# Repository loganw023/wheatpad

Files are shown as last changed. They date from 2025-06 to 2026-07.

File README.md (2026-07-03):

# wheatpad
This is a macropad for personal use. It has six keys, a rotary encoder with a switch, and an OLED screen. I used KMK firmware to code the macropad. I used the macropad as an introduction to PCB design and to increase my CAD experience. 

## Build Photo


## CAD
I used Fusion360 to create my macropad case. There are two parts: a bottom and a top. In the physical model, the PCB will be moved up to allow enough space for keycaps to be pressed. 
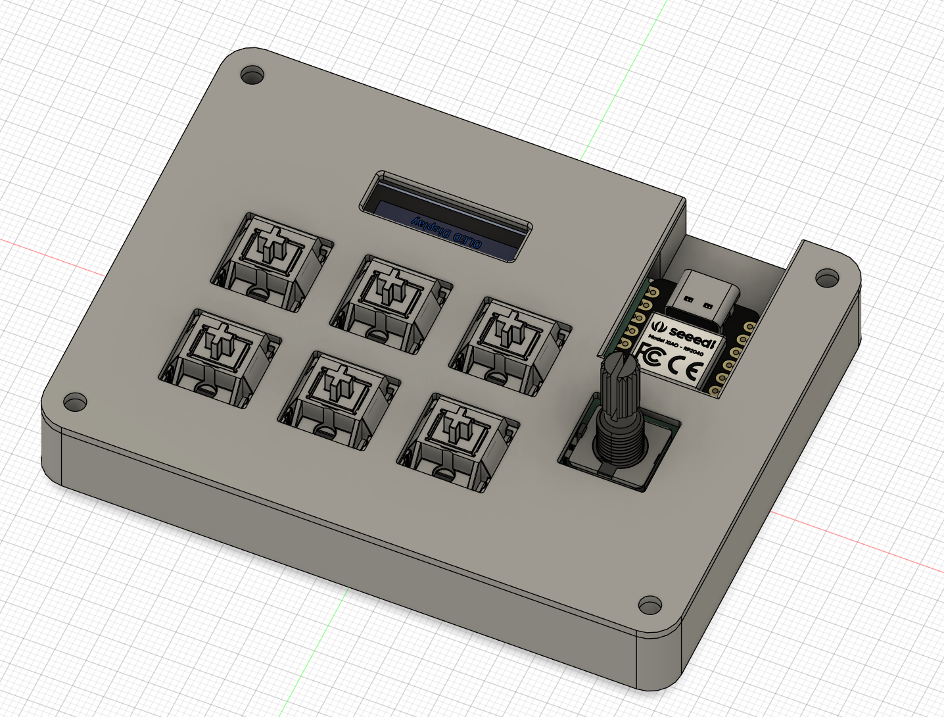
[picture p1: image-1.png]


## PCB
Schematic: 
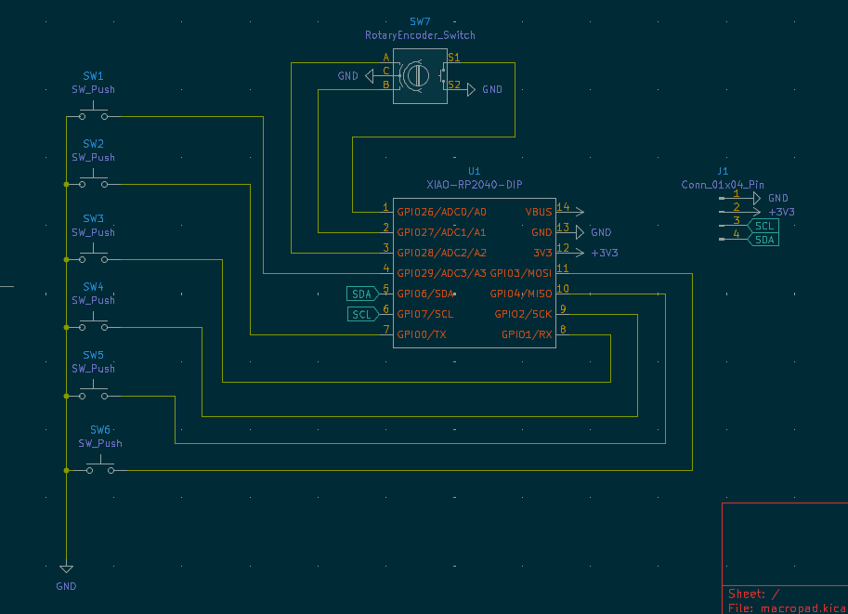
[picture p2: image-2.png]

PCB:
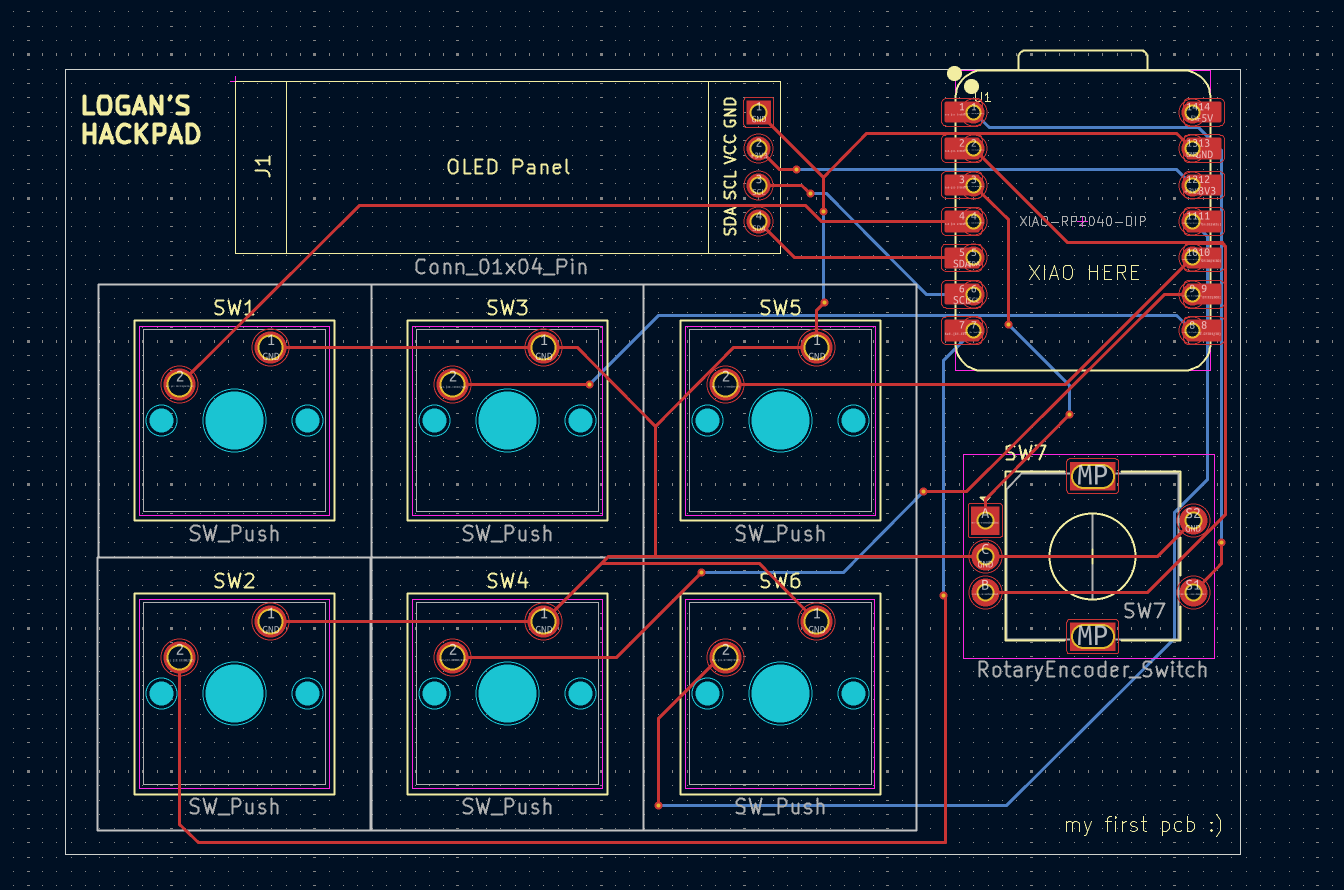
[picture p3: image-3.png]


## Firmware
I updated the firmware for the finished product! 

## BOM
* 6x Cherry MX Switches
* 6x DSA Keycaps
* 4x M3x5x4 Heatset inserts
* 4x M3x16mm SHCS Bolts
* 1x 0.91" 128x32 OLED Display
* 1x EC11 Rotary Encoder
* 1x XIAO RP2040
* 1x Case (2 printed parts)
* 1x Custom PCB

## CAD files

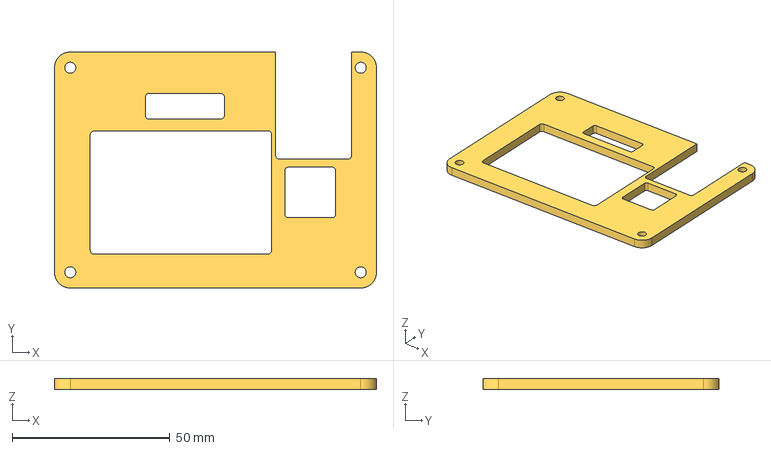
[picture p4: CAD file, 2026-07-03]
CAD/newLid.step
102.0 x 74.8 x 3.50 mm

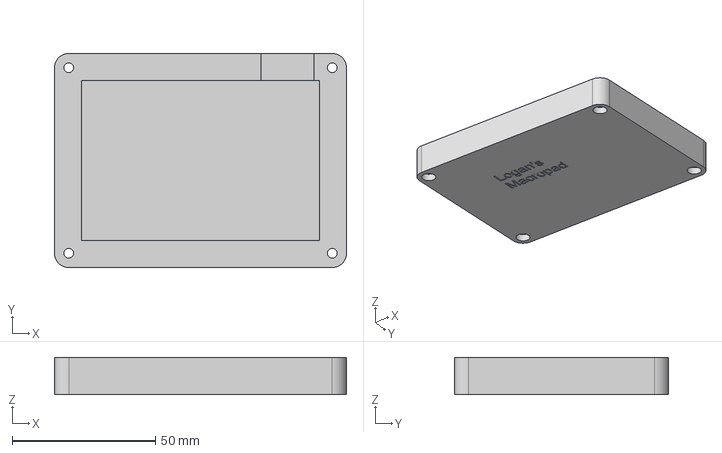
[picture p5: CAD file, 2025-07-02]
Production/Bottom.step
102.0 x 74.8 x 13.0 mm

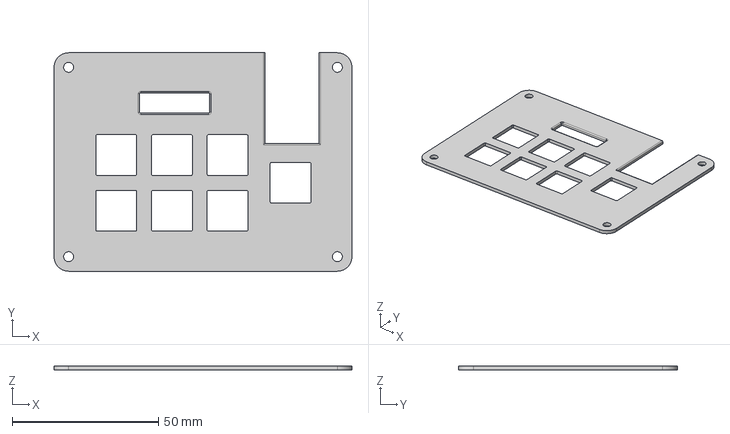
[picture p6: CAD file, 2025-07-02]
Production/Top.step
102.0 x 74.8 x 1.50 mm

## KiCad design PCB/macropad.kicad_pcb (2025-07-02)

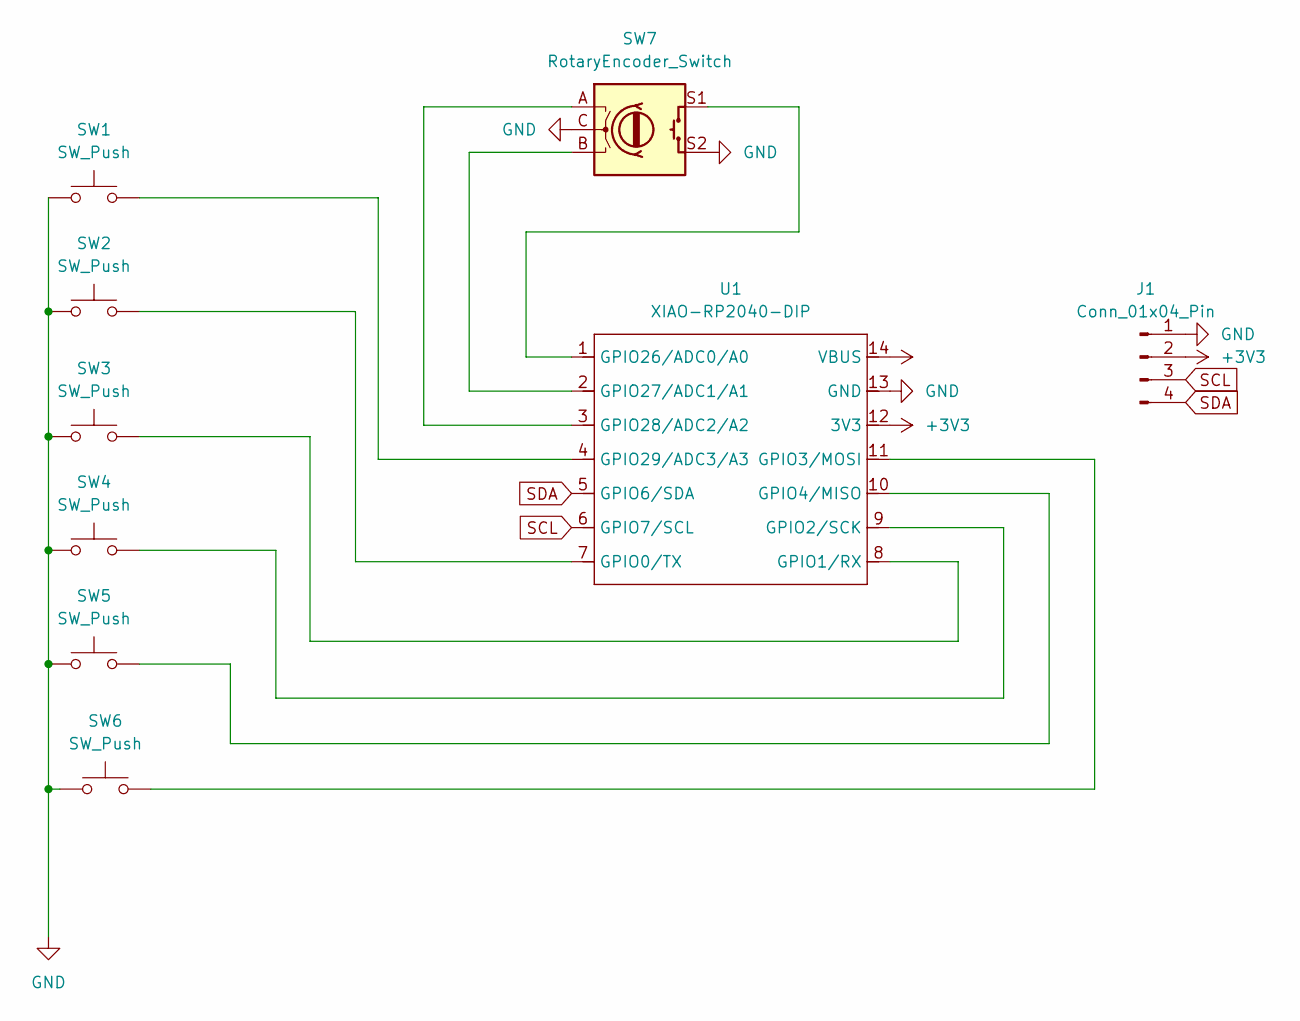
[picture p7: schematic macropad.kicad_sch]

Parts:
J1: Conn_01x04_Pin; SSD1306-0.91-OLED-4pin-128x32
SW1, SW2, SW3, SW4, SW5, SW6: SW_Push; SW_Cherry_MX_1.00u_PCB
SW7: RotaryEncoder_Switch; RotaryEncoder_Alps_EC11E-Switch_Vertical_H20mm
U1: XIAO-RP2040-DIP

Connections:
+3V3: J1.2, U1.12 (3V3)
+5V: U1.14 (VBUS)
GND: J1.1, SW1.1, SW2.1, SW3.1, SW4.1, SW5.1, SW6.1, SW7.C, SW7.S2, U1.13 (GND)
unnamed: SW2.2, U1.7 (GPIO0/TX)
unnamed: SW3.2, U1.8 (GPIO1/RX)
unnamed: SW4.2, U1.9 (GPIO2/SCK)
unnamed: SW6.2, U1.11 (GPIO3/MOSI)
unnamed: SW5.2, U1.10 (GPIO4/MISO)
unnamed: SW7.S1, U1.1 (GPIO26/ADC0/A0)
unnamed: SW7.B, U1.2 (GPIO27/ADC1/A1)
unnamed: SW7.A, U1.3 (GPIO28/ADC2/A2)
unnamed: SW1.2, U1.4 (GPIO29/ADC3/A3)
SCL: J1.3, U1.6 (GPIO7/SCL)
SDA: J1.4, U1.5 (GPIO6/SDA)

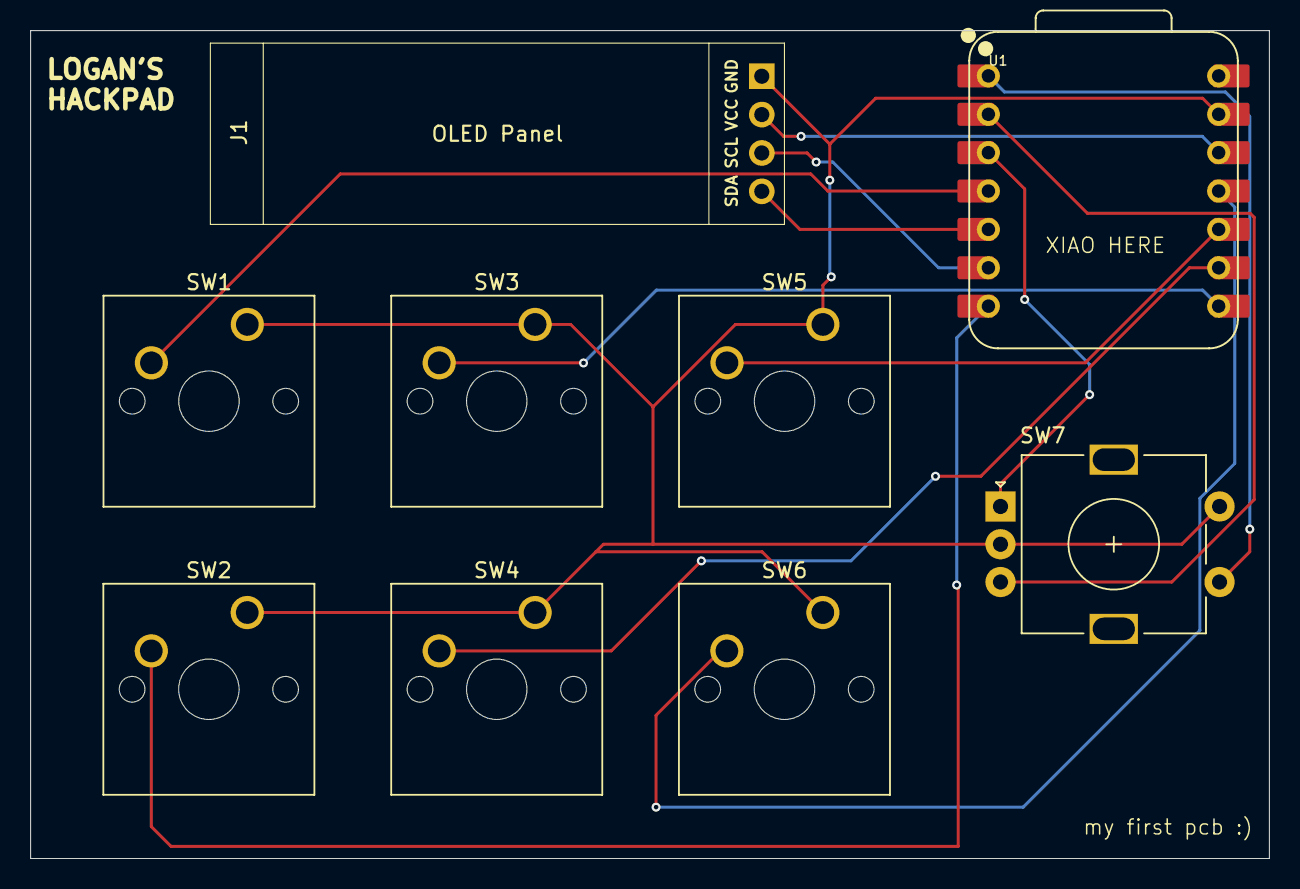
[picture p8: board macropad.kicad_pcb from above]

Board: 2 copper layers, 82.0 x 54.8 mm, 9 parts (0 on the bottom side), 13 nets.

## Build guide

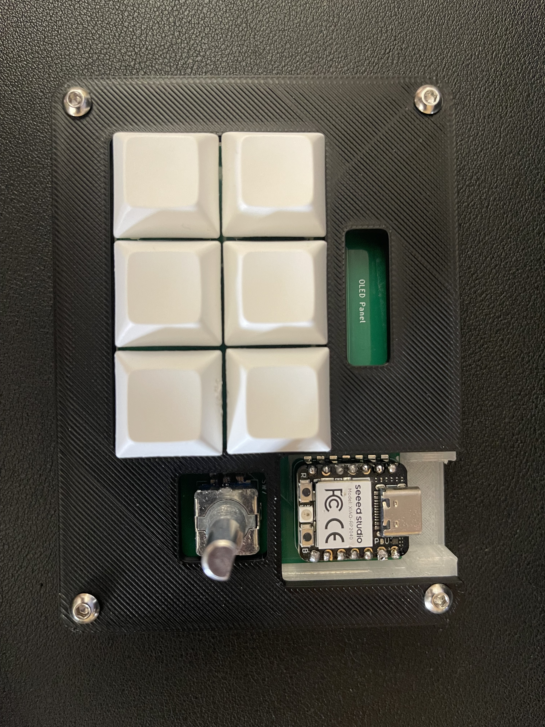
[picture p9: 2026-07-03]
Build Photos/IMG_4601.jpeg

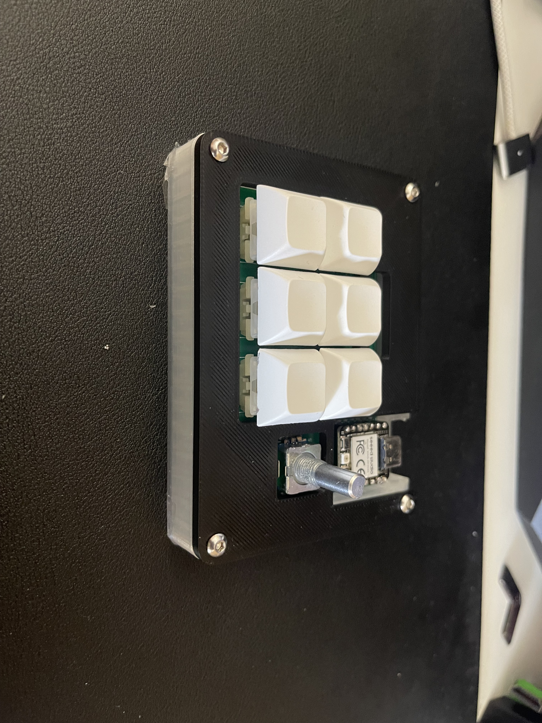
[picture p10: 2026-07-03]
Build Photos/IMG_4600.jpeg

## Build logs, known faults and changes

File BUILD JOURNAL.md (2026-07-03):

# Build Journal

This project is from highway. Last summer, I soldered all the components down onto the PCB, installed circuitpython and copied the firmware, but the macropad did not work, so I put the project on hold for a while. I only picked up the project and finished it during outpost, in which I started building 07/02/2026, and finished 07/03/2026. 

## 07/02/2026

The work outlined was not thoroughly documented, and I only took a few pictures of the end product. The work outlined took place from around 4 pm to 10 pm which entails the troubleshooting effort leading towards a working end item. 

Today, I started by plugging in the macropad, but noticed that the macropad did not work. I ended up fixing a bunch of soldering joints that were poorly done last summer, which I think are a lot cleaner now. When plugging in the macropad again, I noticed that nothing worked. I first thought that this was a firmware issue, so I went through many iterations of the code to attempt to fix the issue, but none of these coding changes caused the macropad to work. When soldering, I realized that I accidently connected two soldering joints on the rotary encoder, being GND and Pin A, which I thought was the issue. I then spent an hour attempting to separate the two joints from each other, which I managed to do, but I destroyed the rotary encoder pins. When going back, I again realized that NOTHING worked once again. From here, I decided to use a multimeter to check if electricity could flow throughout the PCB. I proceeded to perform continuity mode tests as well as accidental ground short tests. The PCB passed all these tests, which made me more confused. I then thought that the issue was the pin assignments, but that also wasn't the issue. I ended up using a paper clip to act as a bridge between the XIAO GND pin and certain GPIO pins mapped to the switches on the XIAO, which caused the letters to be printed, which helped me determine that the issue was most likely broken traces on the PCB, specifically the common GND trace that all my switches were connected to. From here, I used a wire I had from an introductory arduino kit and soldered it between one of the switch's GND pin and the XIAO GND pin. This caused the switches to work. 

## 07/03/2026

Today, I cleaned up the GND wire I added to be more discrete to allow the PCB to fit in the case, and put the PCB in the case and screwed the lid onto the bottom. I realized that I lost the OLED screen the kit came with, but ultimately the screen was not essential to the functionality of the product, so I think it's fine without the OLED. Additionally, the rotary encoder does not work still, which I think is not only because of the mishap with the soldering job, but also because of issues with the traces on the PCB. In the end, the switches still work, which is the main purpose of the macropad for me anyways, so I'm pretty happy with the product!

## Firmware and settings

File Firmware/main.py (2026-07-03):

import board
from kmk.kmk_keyboard import KMKKeyboard
from kmk.scanners.keypad import KeysScanner
from kmk.keys import KC

keyboard = KMKKeyboard()

PINS = [
    board.A3,   # SW1
    board.D6,   # SW2
    board.D7,   # SW3
    board.D8,   # SW4
    board.D9,   # SW5
    board.D10   # SW6
]

keyboard.matrix = KeysScanner(
    pins=PINS,
    value_when_pressed=False, 
    pull=True 
)

keyboard.keymap = [
    [
        KC.A, KC.C, KC.E,
        KC.B, KC.D, KC.G  
    ]
]

if __name__ == '__main__':
    keyboard.go()

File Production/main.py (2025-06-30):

# You import all the IOs of your board
import board
import busio

# These are imports from the kmk library
from kmk.kmk_keyboard import KMKKeyboard
from kmk.scanners.keypad import KeysScanner
from kmk.keys import KC
from kmk.modules.macros import Press, Release, Tap, Macros
from kmk.modules.encoder import EncoderHandler
from kmk.extensions.display import Display, TextEntry
from kmk.extensions.display.ssd1306 import SSD1306

# This is the main instance of your keyboard
keyboard = KMKKeyboard()

# Add the macro extension
macros = Macros()
keyboard.modules.append(macros)

# Add encoder support
encoder_handler = EncoderHandler()
keyboard.modules.append(encoder_handler)

# Define your pins here!
PINS = [board.D3, board.D6, board.D7, board.D8, board.D9, board.D10]

# Configure the encoder stuff
encoder_handler.pins = (
    (board.D2, board.D1, board.D0, False),  # (pin_a, pin_b, pin_button, is_inverted)
)

# Define encoder actions
Zoom_in = KC.LCTRL(KC.EQUAL)
Zoom_out = KC.LCTRL(KC.MINUS)
encoder_handler.map = [
    ((Zoom_out, Zoom_in, KC.NO),),
]

#Configuring the display stuff
bus = busio.I2C(board.GP_SCL, board.GP_SDA)
driver = SSD1306(i2c=bus, device_address=0x3C)

display = Display(
    display=driver,
    width=128,
    height=32,
    flip = False,
    dim_time=10,
    dim_target=0.2,
    off_time=1200,
    brightness=0.8
)

display.entries = [
        TextEntry(text="Logan Macropad", x=64, y=16, x_anchor="M", y_anchor="M"),
]

# Tell kmk we are not using a key matrix
keyboard.matrix = KeysScanner(
    pins=PINS,
    value_when_pressed=False,
)

# Here you define the buttons corresponding to the pins
# Look here for keycodes: https://github.com/KMKfw/kmk_firmware/blob/main/docs/en/keycodes.md
# And here for macros: https://github.com/KMKfw/kmk_firmware/blob/main/docs/en/macros.md
keyboard.keymap = [
    [KC.A, KC.B, KC.C, 
     KC.D, KC.E, KC.F, ]
]

# Start kmk!
if __name__ == '__main__':
    keyboard.go()

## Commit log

2025-07-02 adding my files
    [Bottom.step, Top.step, macropad.kicad_pcb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]
2026-07-03 Updated github with build
    [newLid.step]
